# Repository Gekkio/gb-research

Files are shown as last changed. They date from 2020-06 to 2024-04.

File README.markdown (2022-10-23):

<!--
SPDX-FileCopyrightText: 2020-2022 Joonas Javanainen <joonas.javanainen@gmail.com>

SPDX-License-Identifier: CC0-1.0
-->
# Game Boy hardware research

*Disclaimer: reverse engineering from decap photos of just one layer involves a
lot of guesswork, so there are almost certainly mistakes!*

## Repository contents

* [`mbc1b/`](./mbc1b): Game Boy MBC1B Memory Bank Controller chip
* [`sm83-cpu-core/`](./sm83-cpu-core): Game Boy SM83 CPU core

## License

All assets (e.g. vector and bitmap images) and schematics are licensed under
Creative Commons Attribution 4.0 International.

All code is licensed under either of

 * Apache License, Version 2.0, ([LICENSES/Apache-2.0.txt](LICENSES/Apache-2.0.txt) or http://www.apache.org/licenses/LICENSE-2.0)
 * MIT license ([LICENSES/MIT.txt](LICENSES/MIT.txt) or http://opensource.org/licenses/MIT)

at your option.

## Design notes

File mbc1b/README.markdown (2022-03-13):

<!--
SPDX-FileCopyrightText: 2020-2022 Joonas Javanainen <joonas.javanainen@gmail.com>

SPDX-License-Identifier: CC0-1.0
-->
# Game Boy MBC1B Memory Bank Controller chip



[KiCad Schematic](schematic/MBC1B.pdf)

Many older Game Boy cartridges include an MBC1 chip, which is used to memory
map larger ROM/RAM chips to the limited address space reserved to the cartridge
on Game Boy.

The Game Boy address space has two reserved areas for cartridges:

- a 32 kB "cartridge ROM address range" (0x0000-0x7FFF): essentially a 15-bit
  address + A15 pin used as chip select
- a 8 kB "cartridge RAM address range" (0xA000-0xBFFF): essentially a 13-bit
  address + CS pin used as chip select

In order to use ROM chips larger than 32 kB and/or RAM chips larger than 8 kB,
some kind of mapper chip is required.

For example, if a cartridge has a 128 kB ROM chip, the chip requires a 17-bit
address and would not work alone since the console only provides a 15-bit
address in the ROM address range. This kind of cartridge could wire the low 15
address bits directly to the ROM chip, and the high 2 address bits could
be provided by an MBC1 chip. This concept is called "ROM banking", and the two
extra bits provided by MBC1 are called the "bank number".

Note: There are multiple MBC1 versions and different implementations from
several manufacturers. The chip reverse engineered here is MBC1B manufactured
by NEC.

## Repository contents

- `schematic/`: KiCad schematics
- `MBC1B.svg`: Inkscape SVG with all connections traced and all cells identified
- `MBC1B.jpg`: a stitched photo of a decapped MBC1B die, taken with a 20x microscope objective
- `hdl/mbc1b_tb.vhd`: a VHDL testbench with several tests, also verified
  on a real MBC1B chip using a simple GPIO bit-bang setup
- `hdl/generated/`: a structural VHDL model generated from the schematics using
  Kingfish HDL generator. The main purpose is automated testing via simulation,
  so the model is *not* meant to be readable by humans
- `hdl/cells/`: VHDL models for the standard cells on the chip

## Running the HDL test suite

1. Install [Poetry](https://python-poetry.org/)
2. Install [GHDL](https://github.com/ghdl/ghdl)
3. Run `poetry install` in the `hdl` directory
4. Run `poetry run ./run.py` in the `hdl` directory

## Further reading

- [Game Boy: Complete Technical Reference](https://github.com/Gekkio/gb-ctr): contains a high-level description of MBC1
- [Tauwasser's MBC1 wiki page](https://wiki.tauwasser.eu/view/MBC1): contains technical information and a readable VHDL model of MBC1

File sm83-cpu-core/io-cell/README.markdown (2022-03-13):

<!--
SPDX-FileCopyrightText: 2022 Joonas Javanainen <joonas.javanainen@gmail.com>

SPDX-License-Identifier: CC0-1.0
-->

# SM83 IO cell

<a href="sm83_io_cell.png">

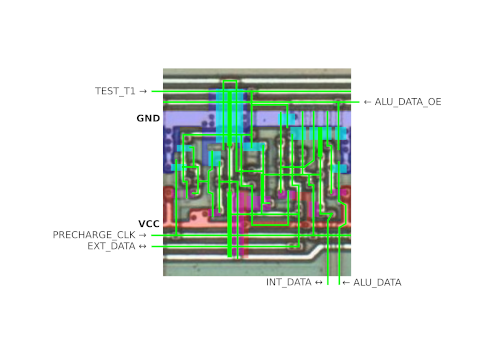
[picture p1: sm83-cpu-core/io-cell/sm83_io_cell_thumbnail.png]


</a>

[sm83_io_cell.svg](sm83_io_cell.svg) is an Inkscape SVG that includes all
traces as labeled objects (not layers!).

## Connections

* **EXT_DATA**: Bidirectional connection to the main SoC data bus
* **INT_DATA**: Bidirectional connection to one of the SM83 CPU core data buses
* **ALU_DATA**: Input connection from the ALU output bus
* **TEST_T1**: Low under normal conditions, but if raised high, isolates the main
  SoC data bus (EXT_DATA) from the CPU core by disabling all EXT_DATA bus circuitry
* **PRECHARGE_CLK**: Clock used for precharging and dynamic logic in the CPU core.
  If low, both EXT_DATA and INT_DATA are pulled high to precharge the parasitic bus
  capacitance, and other bus circuitry is disabled
  If high, a pass transistor between INT_DATA/EXT_DATA is activated
* **ALU_DATA_OE**: If high and ALU_DATA is low, activates a low-side driver on
  the INT_DATA bus. Basically allows data to flow from ALU_DATA to
  INT_DATA/EXT_DATA, but only a low-side driver is used because the target
  buses use precharging

## License

Licensed under Creative Commons Attribution 4.0 International.

The background image is a cropped version of the dmg-cpu-a decap photo from
[siliconpr0n.org](https://siliconpr0n.org/map/nintendo/dmg-cpu-a/), and is used
in accordance to the CC BY 4.0 license.

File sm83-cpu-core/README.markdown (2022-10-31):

<!--
SPDX-FileCopyrightText: 2020-2022 Joonas Javanainen <joonas.javanainen@gmail.com>

SPDX-License-Identifier: CC0-1.0
-->
# Game Boy SM83 CPU core

SGB-CPU 01 chip

Overview of the SoC die with the CPU core highlighted

Overview of SM83 CPU core SVG with one small section highlighted

Zoomed-in detail of a SM83 CPU core section in the SVG

Game Boy consoles use a custom Sharp CPU core that resembles Z80 and 8080 but
is not exactly either. Some people use the name LR35902, but that is actually 
the name of the original Game Boy (DMG) SoC, which includes a huge amount of
other things than just the CPU despite being labeled "DMG-CPU". This is why I
call the chip a System-on-a-Chip (SoC), and the CPU core needs a separate name.

A couple of old Sharp databooks describe a "SM83" CPU core, which happens to
have an instruction set that is a perfect match with the Game Boy CPU. This
exact instruction set is unique and has not been seen in any other CPU cores,
so SM83 is the most probable name based on currently available information.
Personally I actually think that the CPU core might have an even older name,
since some very old Sharp SM-812/SM-813/SM-814 chips seem to have an unnamed
CPU core that seems at least like a relative. Since public information about
these chips is scarce, SM83 is the most accurate name.
You can read further information about this topic at the [NESdev forums](https://forums.nesdev.org/viewtopic.php?p=232656#p232656)

The reverse engineering work is based on an SGB-CPU 01 chip used in the Super
Game Boy. The chip is a DMG-CPU B chip with a different boot ROM, so the are
no relevant differences to DMG-CPU B, and all researched information applies to
the original Game Boy as well.

The HDL model passes the following tests:

- The whole Blargg's cpu_instrs test suite, except "02 - interrupts" which
  requires SoC peripherals and won't work with just the CPU core
- DAA test from [mooneye-test-suite](https://github.com/gekkio/mooneye-test-suite)

## What has been done

- a stitched top photo of the entire SM83 CPU core using a 40x objective
- an SVG file that contains hand-drawn traces of almost all interesting
  signals. Some repetitive areas and signals have not been traced because they
  follow a pattern that is already understood. Note: **the background photo is
  not in the repo** and needs to be downloaded separately from
  [here](https://gekkio.fi/files/decapped-chips/Frankenscope/Nintendo_SGB-CPU_01/)
- a **non-synthesizable** HDL model (written in VHDL) using a "medium
  abstraction level". It's meant for simulation and won't work directly on an
  FPGA. The abstraction level focuses on logical blocks and their connections,
  and does not include every single transistor, or even every single signal
- real-world ROM testing by plugging the CPU core into a "mock SoC" (not
  included in the repo at the moment). The CPU core passes all Blargg's
  cpu_instrs that don't require SoC peripherals. In practice this means
  everything except "02 - interrupts" which only passes partially. Simulating
  cpu_instrs took around 3 hours 20 minutes on my Ryzen 9 5950X machine using a
  single core at 100% the whole time (GHDL does not support multi-core simulation)

## What has not been done

- implementation of propagation delays. Estimating realistic propagation delays
  is complicated, especially due to dynamic logic. So far there has been no
  need, but this may change in the future when more testing is done and
  possible edge-cases are discovered
- perfect names for everything. A lot of effort has been spent on naming
  things, but for example the control unit signals currently have poor names

## What is planned

- KiCad schematics of at least the control unit. They already exist but are
  not ready for release. The hand-written HDL will be replaced with HDL
  generated from the schematics once this is done

## Repository contents

- `SGB-CPU_01_sm83_core_40x.svg`: Inkscape SVG with most of the CPU core traced
  and identified. Download the background image [here](https://gekkio.fi/files/decapped-chips/Frankenscope/Nintendo_SGB-CPU_01/)
  separately and put it in the same folder to use it
- `hdl/`: a **non-synthesizable** HDL model of the SM83 CPU core
- `io-cell/`: a separate description of the "I/O cell" that connects the SoC
  data bus to the SM83 CPU core internal data buses

## Running the HDL test suite

1. Install [Poetry](https://python-poetry.org/)
2. Install [GHDL](https://github.com/ghdl/ghdl)
3. Run `poetry install` in the `hdl` directory
4. Run `poetry run test` in the `hdl` directory

## Running a test ROM

1. Install [Poetry](https://python-poetry.org/)
2. Install [GHDL](https://github.com/ghdl/ghdl)
3. Run `poetry install` in the `hdl` directory
4. Place a test ROM file to the `hdl` directory and name the file `test.gb`
5. Run `poetry run rom` in the `hdl` directory

The `poetry run rom` command runs [VUnit](https://github.com/VUnit/vunit) and accepts various extra arguments, for example:

- `--help`: display help
- `-v`: enable verbose mode which displays some logging information
- `-g`: open simulator GUI with test / waveform

The test ROM execution is terminated when any of these conditions is true:

- 100 000 000 instructions have been executed
- 60 seconds of "emulated time" has been reached
- a self-pointing JR opcode is fetched (= infinite loop)
- a self-pointing JP opcode is fetched (= infinite loop)

## Further reading

- [Game Boy: Complete Technical Reference](https://github.com/Gekkio/gb-ctr):
  contains a high-level description of the CPU core and its instruction set

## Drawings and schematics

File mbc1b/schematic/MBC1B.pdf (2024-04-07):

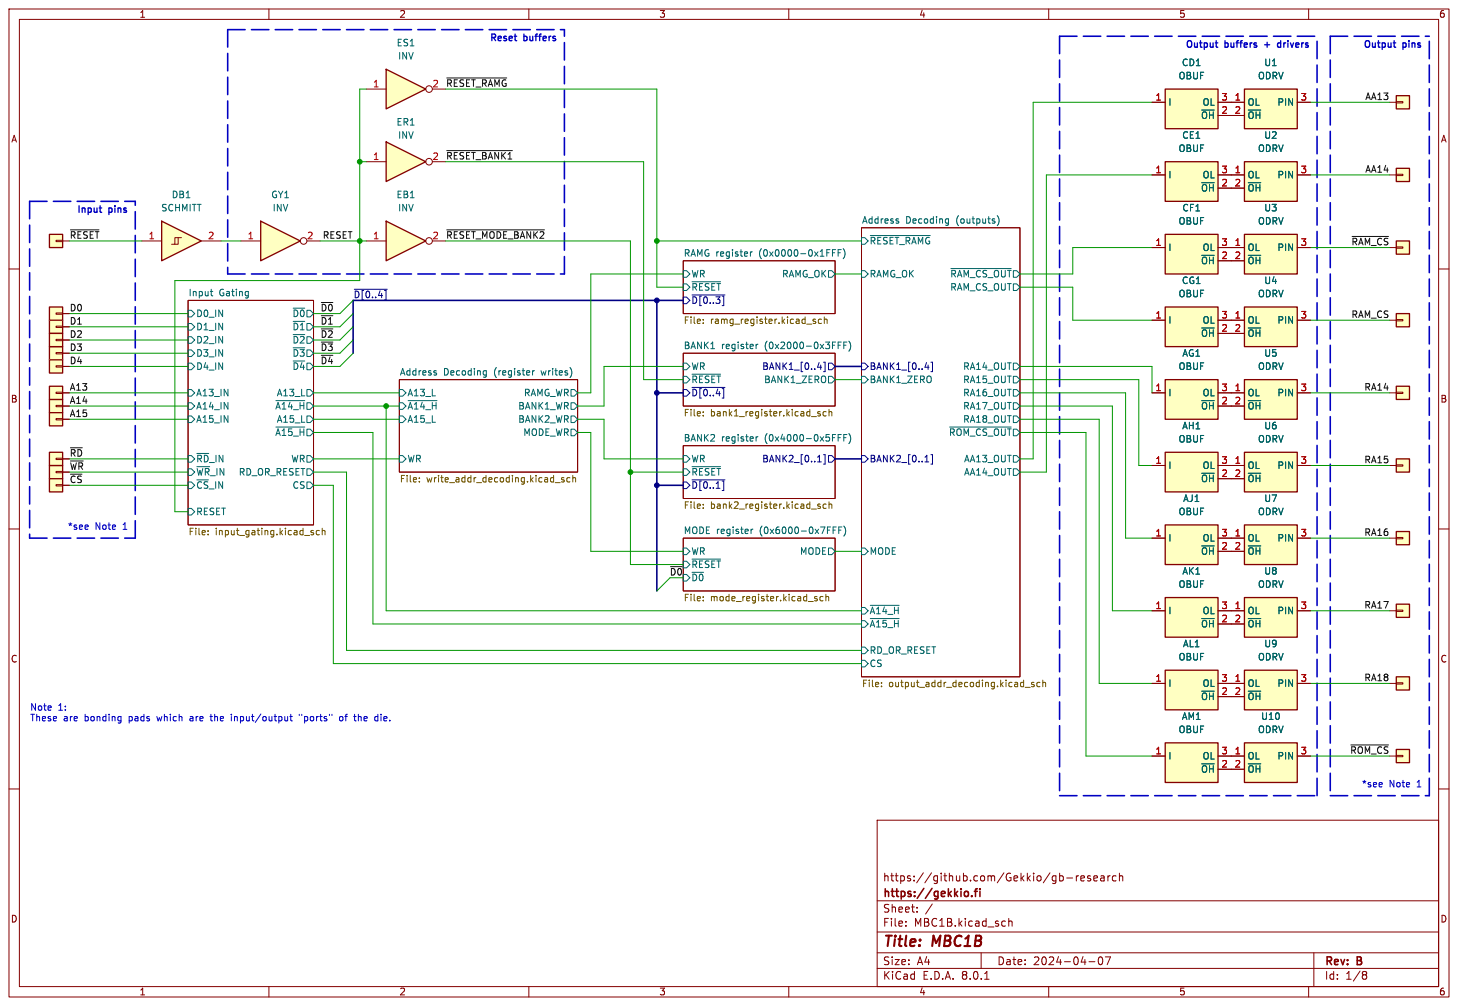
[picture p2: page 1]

https://github.com/Gekkio/gb-research
File: MBC1B.kicad_sch Sheet: / https://gekkio.fi

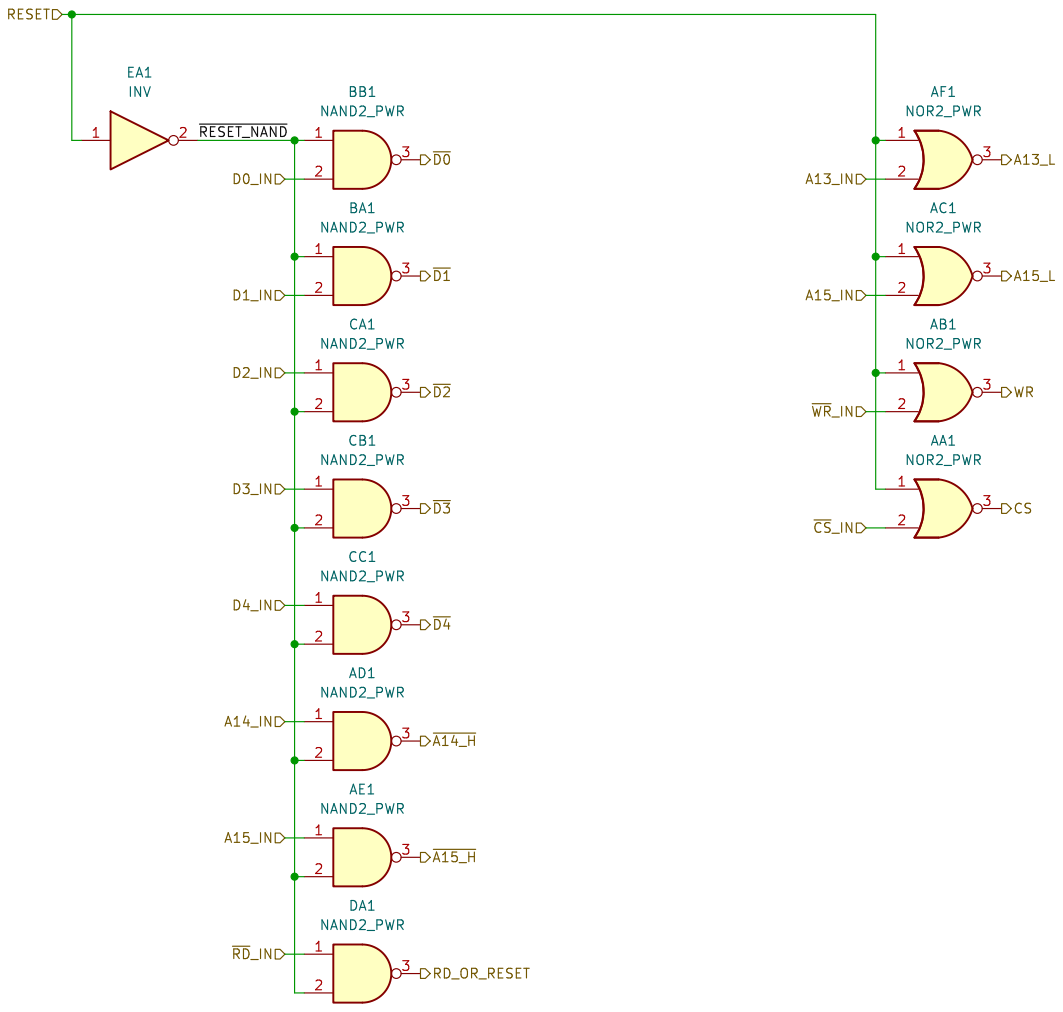
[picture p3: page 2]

https://gekkio.fi
Id: 2/8 Title: MBC1B - Input Gating

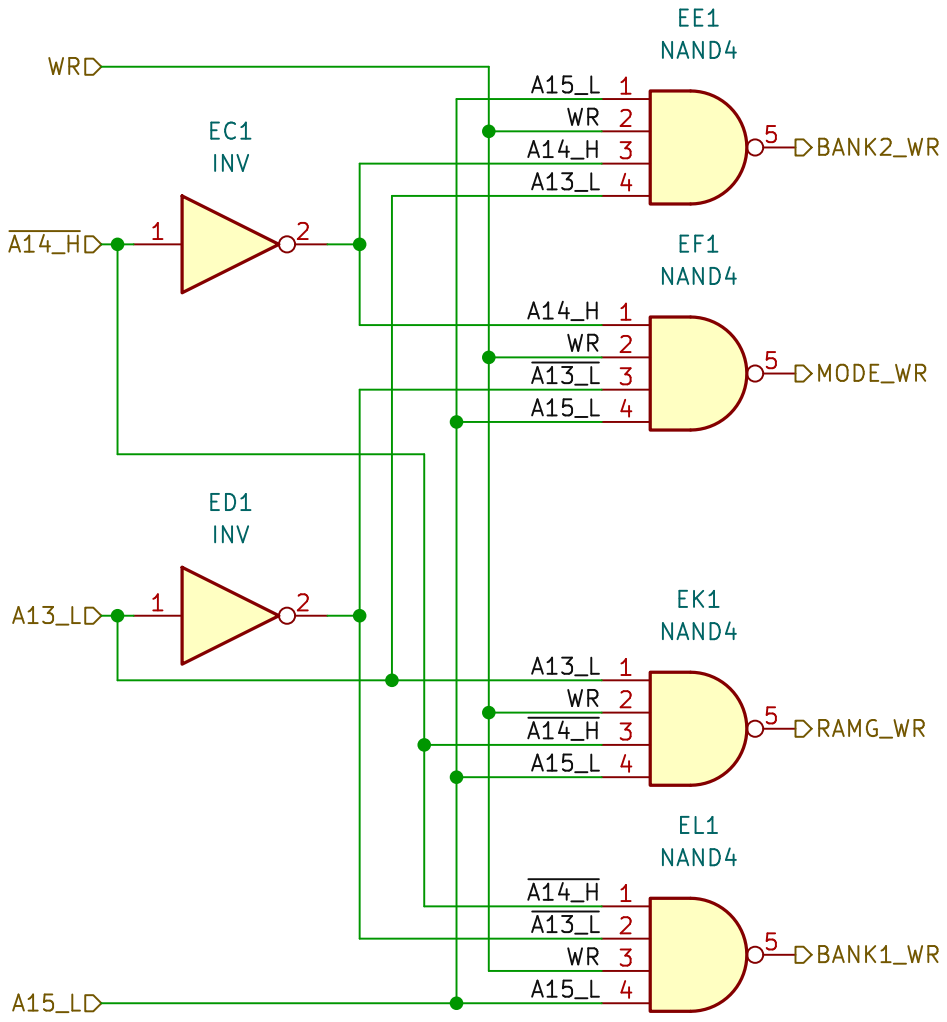
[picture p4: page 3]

https://github.com/Gekkio/gb-research
https://gekkio.fi

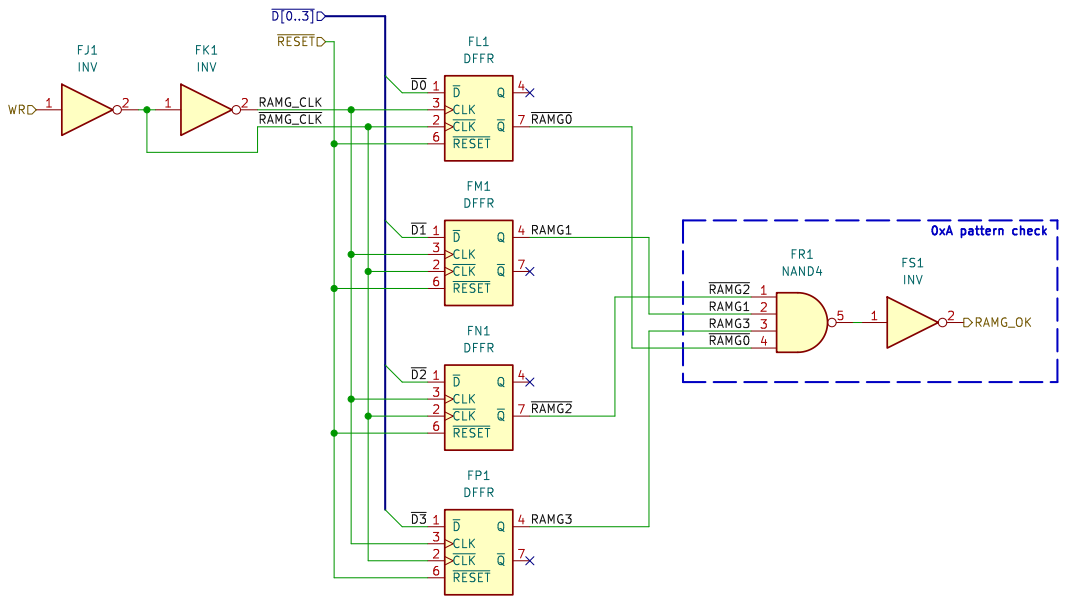
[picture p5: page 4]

https://github.com/Gekkio/gb-research
https://gekkio.fi
Id: 4/8 Title: MBC1B - RAMG register (0x0000-0x1FFF) File: ramg_register.kicad_sch Sheet: /RAMG register (0x0000-0x1FFF)/

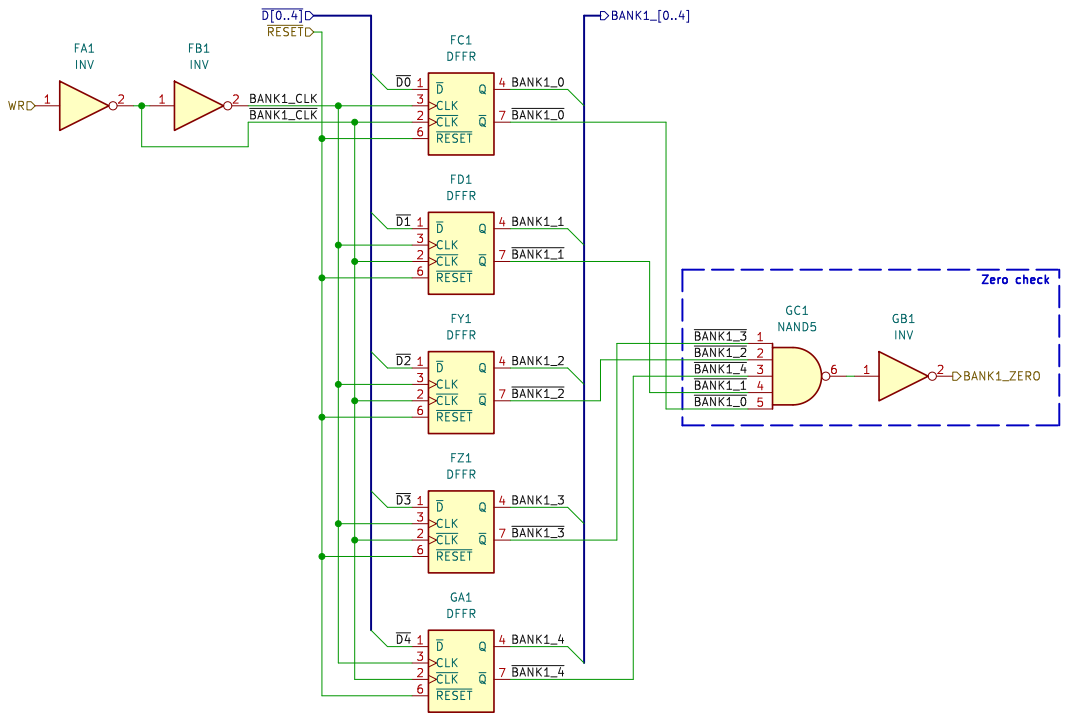
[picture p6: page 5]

~{BANK1_2} 2
~{BANK1_4} 3
~{BANK1_1} 4
~{BANK1_0} 5

https://github.com/Gekkio/gb-research
https://gekkio.fi

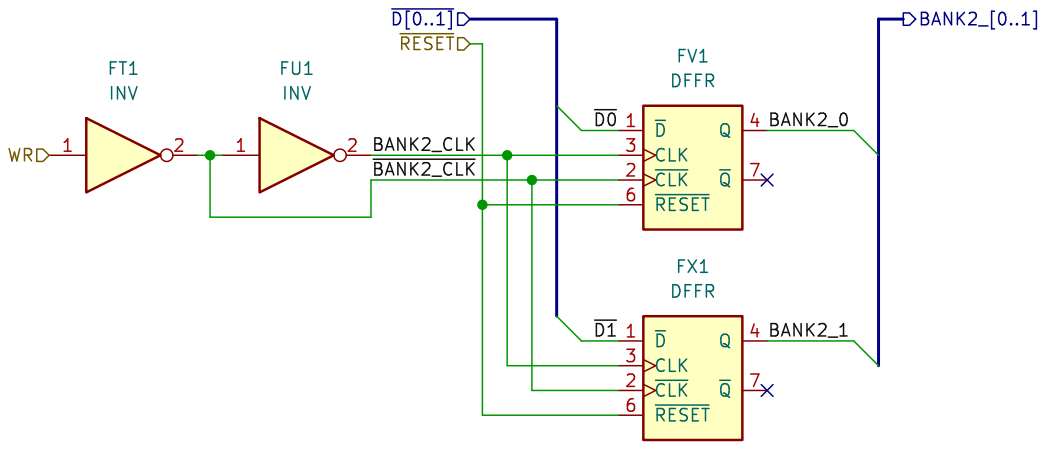
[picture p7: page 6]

https://github.com/Gekkio/gb-research
https://gekkio.fi
Id: 6/8 Title: MBC1B - BANK2 register (0x4000-0x5FFF) File: bank2_register.kicad_sch Sheet: /BANK2 register (0x4000-0x5FFF)/

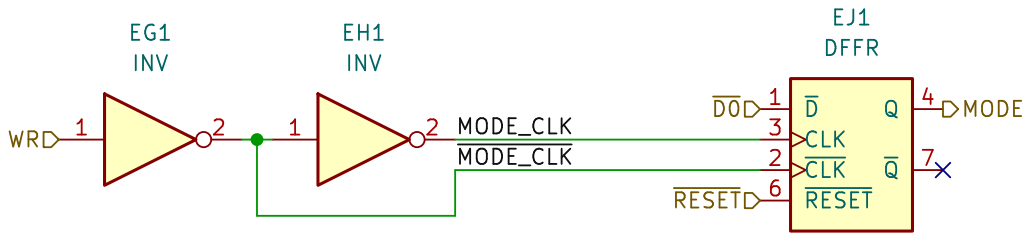
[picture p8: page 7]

https://github.com/Gekkio/gb-research
https://gekkio.fi

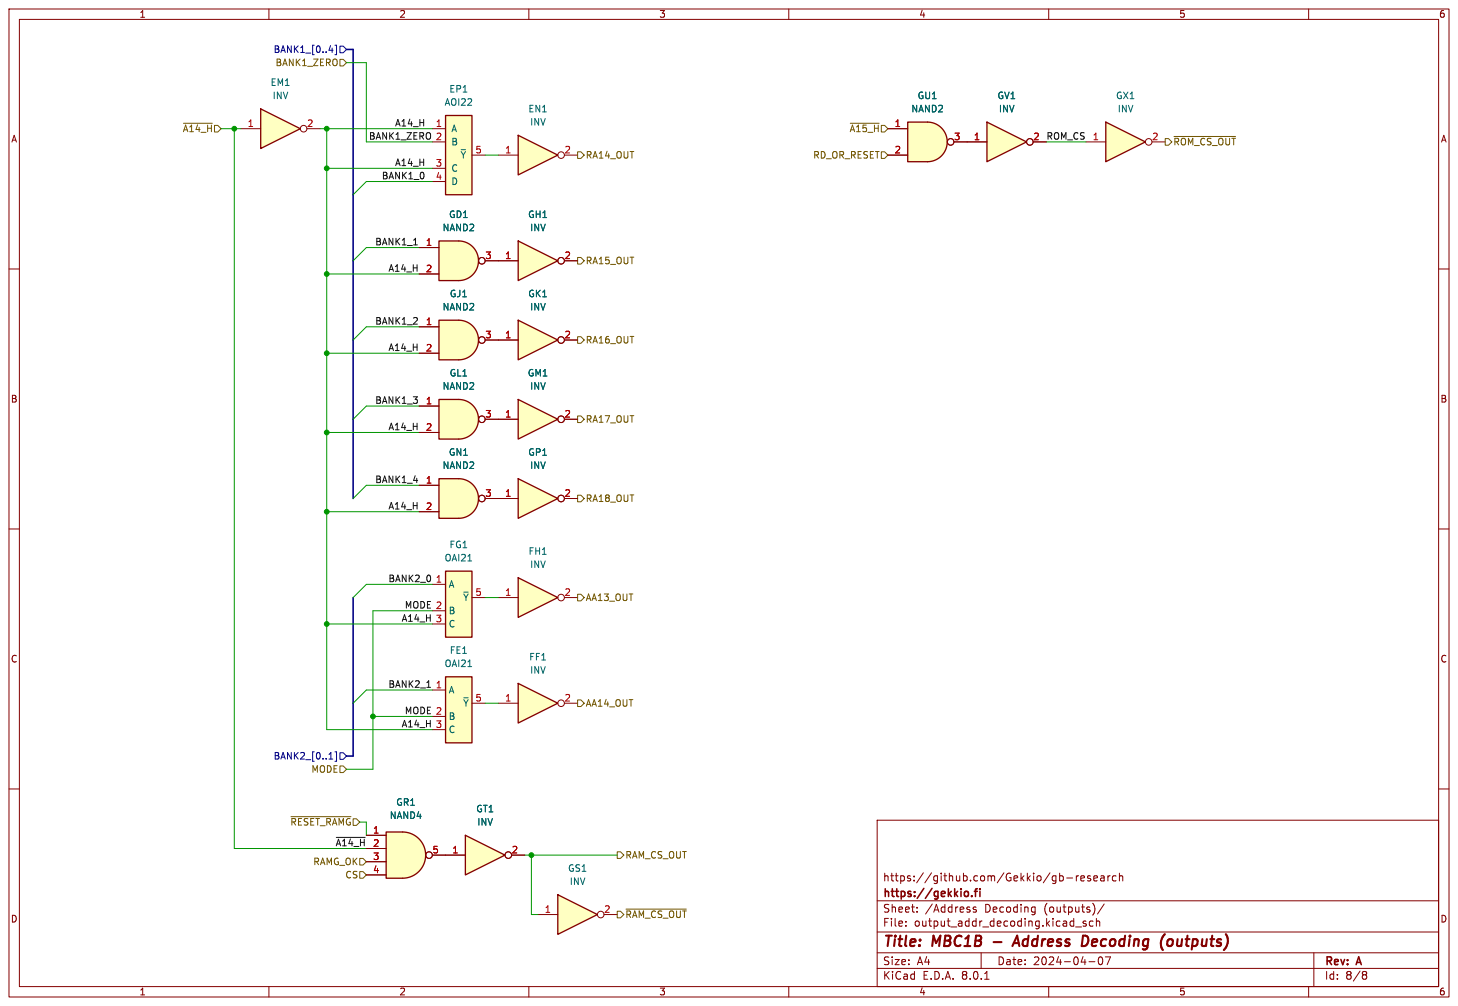
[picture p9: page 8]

https://github.com/Gekkio/gb-research A

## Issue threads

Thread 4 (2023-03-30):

MGB-CPU-01 and MGB-ECPU-01 diference

Dr-Wily, 2023-03-30:
Hello there !

Can you say me what the diference between MGB-CPU-01 and MGB-ECPU-01 motherboard ?

I know LCPU mobo add the LED and change power board layout in second revision, but ECPU doesn't really look different from the first MGB-CPU-01 motherboard.

Have you the clue ?

Thanks ;)

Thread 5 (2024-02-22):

SM83: irq_ack

paulb-nl, 2024-02-22:
First of all thank you for your hard work reverse engineering the SM83.

I encountered an issue with `irq_ack`:
https://github.com/Gekkio/gb-research/blob/a58ce2a27596aed69cc012ddab5d516ca3b201f6/sm83-cpu-core/hdl/interrupts.vhd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

`irq_ack` goes high during cycle `int_s110`. This means it goes high when PHI is high.

`irq_latch` is latched when PHI is high. This makes sense because PHI stays high when the CPU is halted.

The issue is that this way `irq_ack` acknowledges the IRQ when PHI is high and so `irq_latch` immediately goes low before the address is read during `writeback`. It will always jump to address $0000.

Most likely it should be like this:
````vhdl
irq_ack <= irq_prio and int_s110 and writeback;
````
This way it acknowledges the IRQ when PHI is low and `irq_latch` has stopped latching.

PS `irq_prio` is a logic vector and `int_s110` is a single logic signal. It is strange that these can be simply ANDed together. VHDL is usually very strict.

Gekkio, 2024-02-22:
Good catch! You're 100% correct with your reasoning and I've fixed this in my private repo but unfortunately haven't backported the fix here. :sweat_smile:

The influence of `writeback` is indeed missing, and it's actually missing from all of the `irq_prio` signals and not `irq_ack`. Every `irq_prio` signal uses dynamic logic, and they're in precharge state (output=0) when `writeback=0` and evaluation state otherwise.

I'll fix it and maybe merge #3 first to give this public repo a bit more love...

PS. I think that's a VHDL 2008 addition, and basically the standard logical operators have extra overloads to handle the special case where you apply it to a vector and a single bit.

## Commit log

2020-11-18 Add instruction decoder stage 2
2022-03-13 Release: MBC1B
    [MBC1B.kicad_sch, bank1_register.kicad_sch, bank2_register.kicad_sch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]
2022-10-22 Remove old instruction decoder stage 2 traces
2022-10-23 Add SM83 interrupts section HDL
2022-12-04 Fix typo in interrupt address calculation
2024-04-07 Update MBC1B schematic with latest kingfish compatibility
    [MBC1B.kicad_sch, bank1_register.kicad_sch, bank2_register.kicad_sch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]
